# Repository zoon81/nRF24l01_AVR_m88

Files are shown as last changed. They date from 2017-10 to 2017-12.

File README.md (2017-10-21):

### Intro
This project was made as an experiment with nRF24l01+ radios.This is a powerfull and cheap wireless interface for any microcontroller project.<br />
I trying to design and make a radio controllerd r/c car.I have everything exept the controllers (receiver and transmitter).
I going to use an ATMEGA88PA micro in the trasmitter and in the receiver too.<br />
### Features
  PWM controlled speed, left/right turn, front lights<br />
  Handbreak<br />
  Out of range detection<br />
  Battery status indicator<br />
### Source code structure
  HAL       --- Hardware Abstraction Layer, low level peripherial drivers<br />
  Drivers   --- External device driver like the nRF24l01 radio<br />
  Utils     --- Everything else<br />

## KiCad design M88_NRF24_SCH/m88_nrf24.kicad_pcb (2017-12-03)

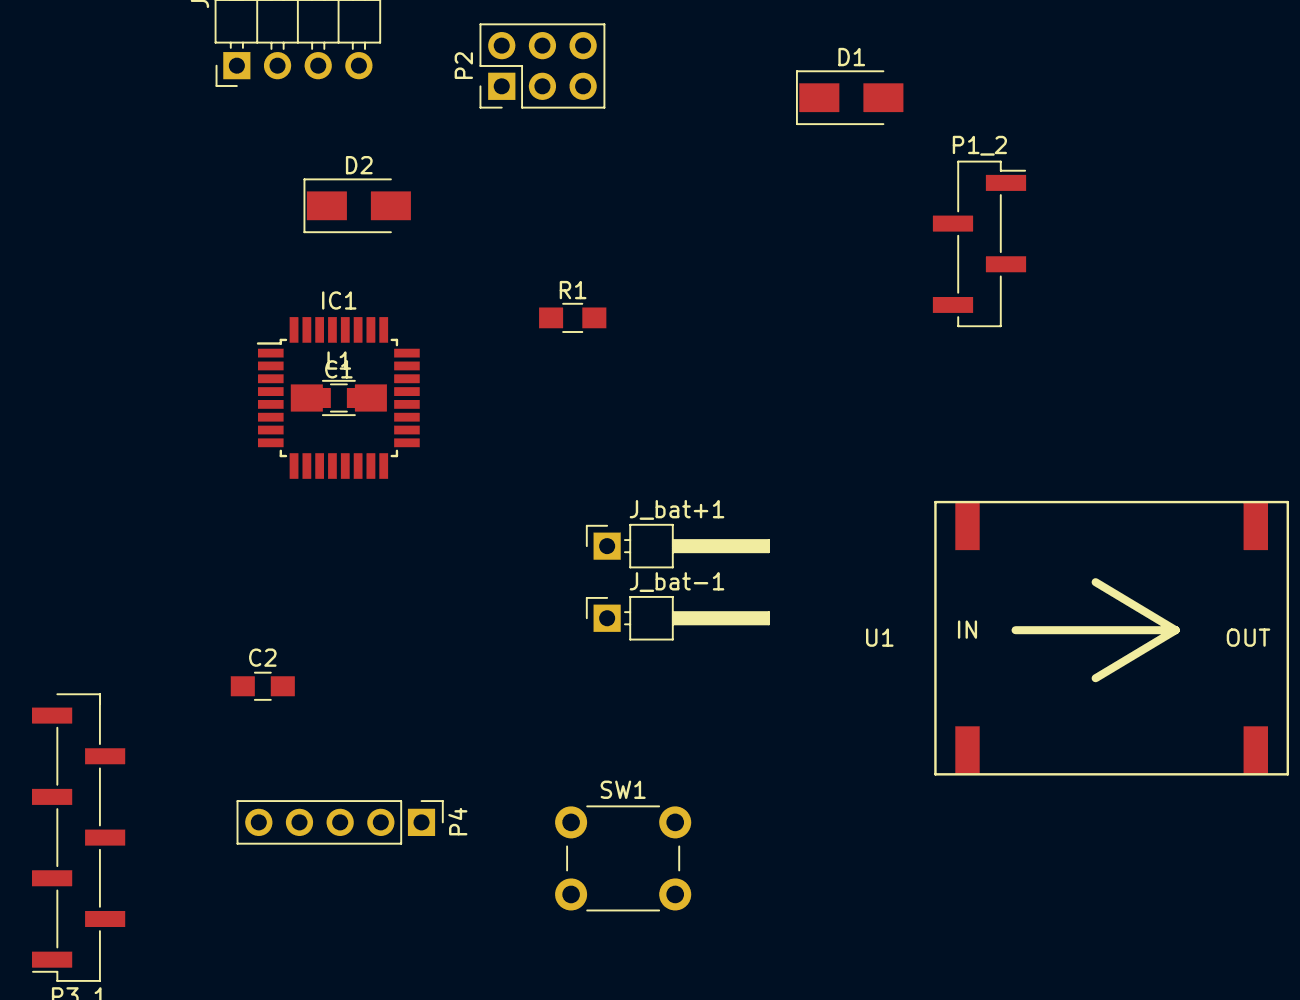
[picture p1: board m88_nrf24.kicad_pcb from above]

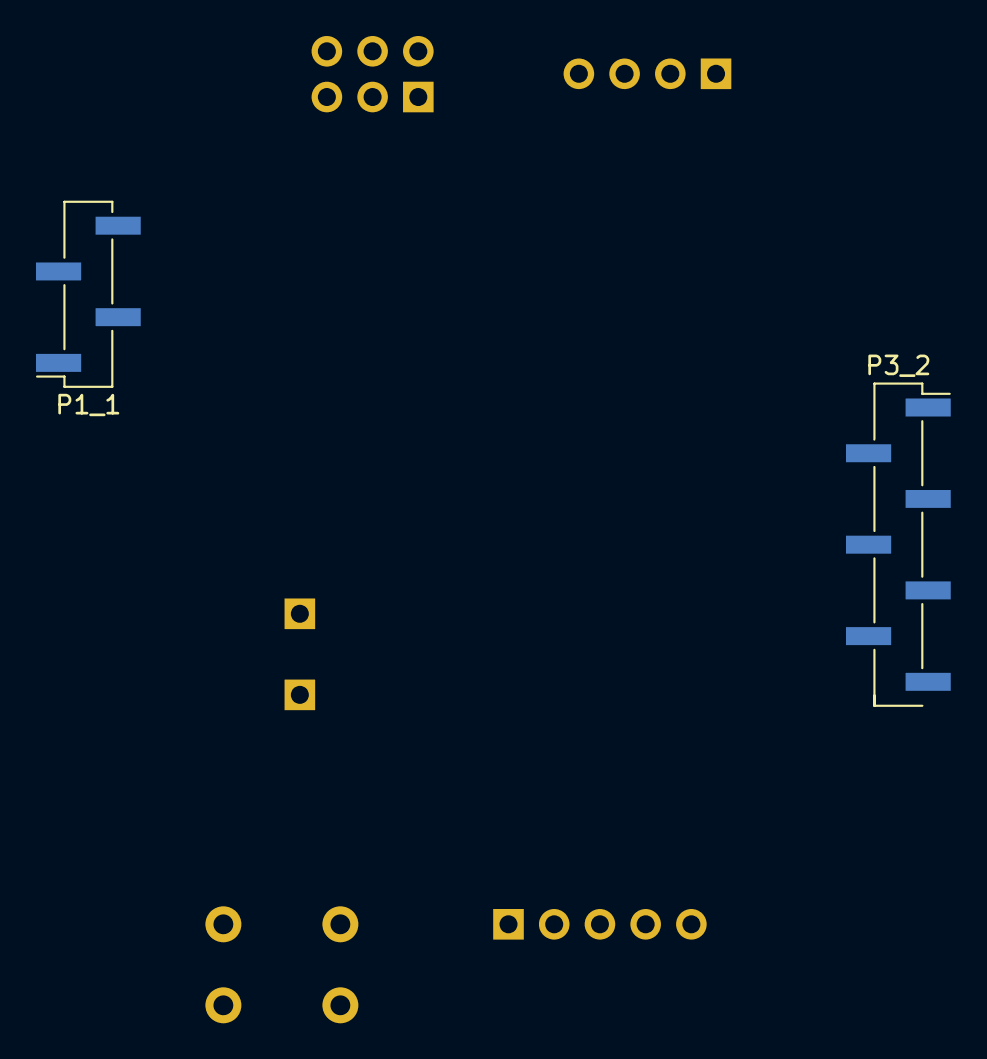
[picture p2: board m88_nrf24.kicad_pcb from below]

Board: 2 copper layers, 18 parts (2 on the bottom side), 28 nets, no tracks yet.

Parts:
C1: 100nF; C_0805_HandSoldering
C2: 0.1uF; C_0805_HandSoldering
D1, D2: D; D_SMA
IC1: ATMEGA88-A; TQFP-32_7x7mm_Pitch0.8mm
J5: Conn_DISP; Pin_Header_Angled_1x04_Pitch2.54mm
J_bat+1: Conn_01x01; Pin_Header_Angled_1x01_Pitch2.54mm
J_bat-1: Conn_01x01; Pin_Header_Angled_1x01_Pitch2.54mm
L1: 10uH; L_1206_HandSoldering
P1_1: NRF_CONN_P1; Pin_Header_Straight_1x04_Pitch2.54mm_SMD_Pin1Right
P1_2: NRF_CONN_P2; Pin_Header_Straight_1x04_Pitch2.54mm_SMD_Pin1Right
P2: ISP_CON; Pin_Header_Straight_2x03_Pitch2.54mm
P3_1, P3_2: Remote_CONN; Pin_Header_Straight_1x07_Pitch2.54mm_SMD_Pin1Right
P4: SERIAL_PORT; Pin_Header_Straight_1x05_Pitch2.54mm
R1: 10K; R_0805_HandSoldering
SW1: SW_DIP_x01; SW_PUSH_6mm_h13mm
U1: mp1584_module

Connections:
/ADC0: IC1.23, P3_2.4
/ADC1: IC1.24, P3_2.5
/ADC6: IC1.19, P3_1.7
/ADC7: IC1.22, P3_1.1
/DTR: C2.2, P4.4
/GPIO_PB0: IC1.12, P1_1.2
/GPIO_PB1: IC1.13, P1_2.2
/GPIO_PB7: IC1.8, P3_1.2
/GPIO_PC2: IC1.25, P3_2.2
/GPIO_PC3: IC1.26, P3_2.1
/GPIO_PD2_INT0: IC1.32, P1_2.4
/GPIO_PD4: IC1.2, P3_1.6
/GPIO_PD5: IC1.9, P3_1.5
/GPIO_PD6: IC1.10, P3_1.3, P3_1.4
/I2C_SCL: IC1.28, J5.3
/I2C_SDA: IC1.27, J5.2
/ISP_MISO: IC1.15, P1_2.3, P2.1
/ISP_MOSI: IC1.16, P1_1.4, P2.4
/ISP_SCK: IC1.17, P1_1.3, P2.3
/MCU_RESET: C2.1, IC1.29, P2.5, R1.2, SW1.1
/RXD: IC1.30, P4.3
/TXD: IC1.31, P4.2
/VCC_ISP: D1.2, P2.2
/VCC_SER: D2.2, P4.1
GND: C1.2, IC1.3, IC1.5, IC1.21, J5.4, J_bat-1.1, P1_1.1, P2.6, P3_2.6, P4.5, SW1.2, U1.1, U1.3
unnamed: C1.1, IC1.18, IC1.20, L1.1
unnamed: J_bat+1.1, U1.2
VCC: D1.1, D2.1, IC1.4, IC1.6, J5.1, L1.2, P1_2.1, P3_2.7, R1.1, U1.4

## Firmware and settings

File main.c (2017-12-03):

/*
 * main.c
 *
 *  Created on: Oct 15, 2017
 *      Author: t400
 */

#include "main.h"

struct payload payload;
uint8_t *adcdata_dest_array[] = {&payload.direction, &payload.speed, &payload.frontlight};
uint8_t adcdata_source_array[] = {VR1_DIRECTION_Y_ADC, VR3_SPEEDCONTROL_ADC, VR4_LIGTHCONTROL_ADC};
uint8_t adcdata_index = 0;
volatile uint8_t packet_sent = 0;

int main()
{

    // Prescaller 1024, CTC mode, interrupt on every ~1000ms
    OCR1A = 7812;
    TCCR1B |= BIT(CS12) | BIT(CS10) | BIT(WGM12);
    TIMSK1 = BIT(OCIE1A);

    //ADC init in ISR mode
    ADMUX |= BIT(REFS0) | BIT(ADLAR);
    ADCSRA |= BIT(ADEN) | BIT(ADPS2) | BIT(ADPS1) | BIT(ADPS0) | BIT(ADIE);
    DIDR0 = 0xFF;
    adc_startconversion(adcdata_source_array[0]); //start rolling, ISR will take controll
    UARTInit();
    adc_init();
    nRF2401_init(NRF_CSN_1, NRF_CE_1);
    nRF2401_reset_IRQ(NRF_CSN_1);
    UARTSendString("  NRF_Config : ");
    UARTSend_uint8(nRF_2401_reg_read(CONFIG, NRF_CSN_1));
    UARTSendString("  NRF_Status : ");
    UARTSend_uint8(nRF_2401_reg_read(STATUS, NRF_CSN_1));

    sei();

    while (1)
    {
        if (packet_sent)
        {
            UARTSendString("Radio status : ");
            UARTSend_uint8(nRF_2401_reg_read(STATUS, NRF_CSN_1));
            UARTSendString("  VR2_x : ");
            UARTSend_uint8(payload.direction);
            UARTSendString("  VR3 : ");
            UARTSend_uint8(payload.speed);
            UARTSendString("  VR4 : ");
            UARTSend_uint8(payload.frontlight);
            UARTSendString("\n\r");
            packet_sent = 0;
        }
    }

    return 0;
}
ISR(TIMER1_COMPA_vect)
{
    if (adcdata_index == 3)
    {
        // UARTSendString("\n\rTIM\n\r");
        payload.header_status = (HEADER_CONTROLLING << HEADER_OFFSET);
        payload.header_status |= switch_values();
        adcdata_index = 0;
        adc_startconversion(adcdata_source_array[0]);
        nRF2401_transmit_payload(&payload, NRF_CSN_1, NRF_CE_1);
        nRF2401_reset_IRQ(NRF_CSN_1);
        
        packet_sent = 1;
    }
    
}

ISR(ADC_vect)
{
    // UARTSendString("\n\rADC\n\r");
    //store the adc result in a designed variable
    *adcdata_dest_array[adcdata_index] = ADCH;
    //If we reach 4 as index we are done, the timer interupt will restarting the conversion
    if (adcdata_index < 3)
    {
        adcdata_index++;
        adc_startconversion(adcdata_source_array[adcdata_index]);
    }
}
void init_switch()
{
    // PD3-PD7 input
    SW_DDR &= ~(0xf8);
}
uint8_t switch_values()
{
    uint8_t pinvalue = (PIND >> 3);
    return pinvalue;
}

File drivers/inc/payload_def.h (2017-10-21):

#ifndef INC_PAYLOAD_DEF_H_
#define INC_PAYLOAD_DEF_H_
#include "main.h"

#define payload_len 5
// analog sticks definition
#define VR2_X_ADC               ADC0
#define VR1_DIRECTION_Y_ADC     ADC1
#define VR4_LIGTHCONTROL_ADC    ADC2
#define VR3_SPEEDCONTROL_ADC    ADC3
// package type definision
#define HEADER_OFFSET       6
#define HEADER_PING         0
#define HEADER_CONTROLLING  1
#define HEADER_GETSTATUS    2
// switch definitions
#define SW_DDR              DDRD
#define SW_PORT             PORTD
#define sw_ststrim_l        PD3
#define sw_ststrim_r        PD4
#define sw_sw2_a            PD5
#define sw_sw2_b            PD6
#define sw_sw2_c            PD7

//header_status variable holds header status and button status. first 2 bit,next 2 bit sw2 state 00 for A, 01 for B, 11 for C. next bit is P02 button, next bit is P05 button 
// Like H H X X A B C L R (bit5 and bit4 not defined yet)
struct payload
{
    uint8_t header_status;
    uint8_t frontlight;
    uint8_t speed;
    uint8_t direction;
};

#endif

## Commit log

2017-10-20 remote_controller integration testing, nonblocking adc conversation, radio communication package definition
2017-11-01 Initial Schemtic added
    [m88_nrf24.kicad_pcb, m88_nrf24.sch]
2017-11-03 Updated schematic
    [m88_nrf24.kicad_pcb, m88_nrf24.sch]
